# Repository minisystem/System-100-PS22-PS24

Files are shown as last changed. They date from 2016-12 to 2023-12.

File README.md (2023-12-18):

Roland System 100 Model 101/102 Power Supply Replacement
============

Replaces Roland part # PS22 (110V) or PS24 (220V). I had a Model 102 come in that was missing its power supply so I designed a replacement. It is a straight clone of the schematic from the Model 102 service manual. The BOM from the service manual can be used directly with the exception of the 2SD234 power transistors (replaced with TIP31A equivalent) and the diode bridges (replaced with individual 1N4003). 

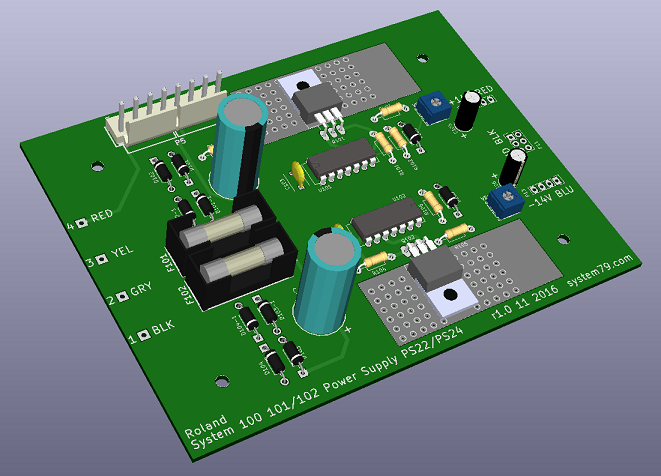
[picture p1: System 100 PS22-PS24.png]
orthoview


EDA files generated in KiCad 4.0.2. Schematic library here: https://github.com/minisystem/MyKicadLibraries/blob/master/MySynthParts.lib

KiCad GitHub libraries required as well. :/

0.156" MTA header: Molex part # 0009652088
trimmers: Bourns 3362P or equivalent

There are large copper pours top and bottom that were intended to be used as heatsinks, but they are almost certainly inadequate. Use a large external heat sink for each power transistor. The orignal heatsinks will work fine.

Mounting holes match original power supply.

Hardware design by Minisystem: jeff@minisystem.ca 

LICENSE
=======
cc-by-nc-sa
https://creativecommons.org/licenses/by-nc-sa/4.0/

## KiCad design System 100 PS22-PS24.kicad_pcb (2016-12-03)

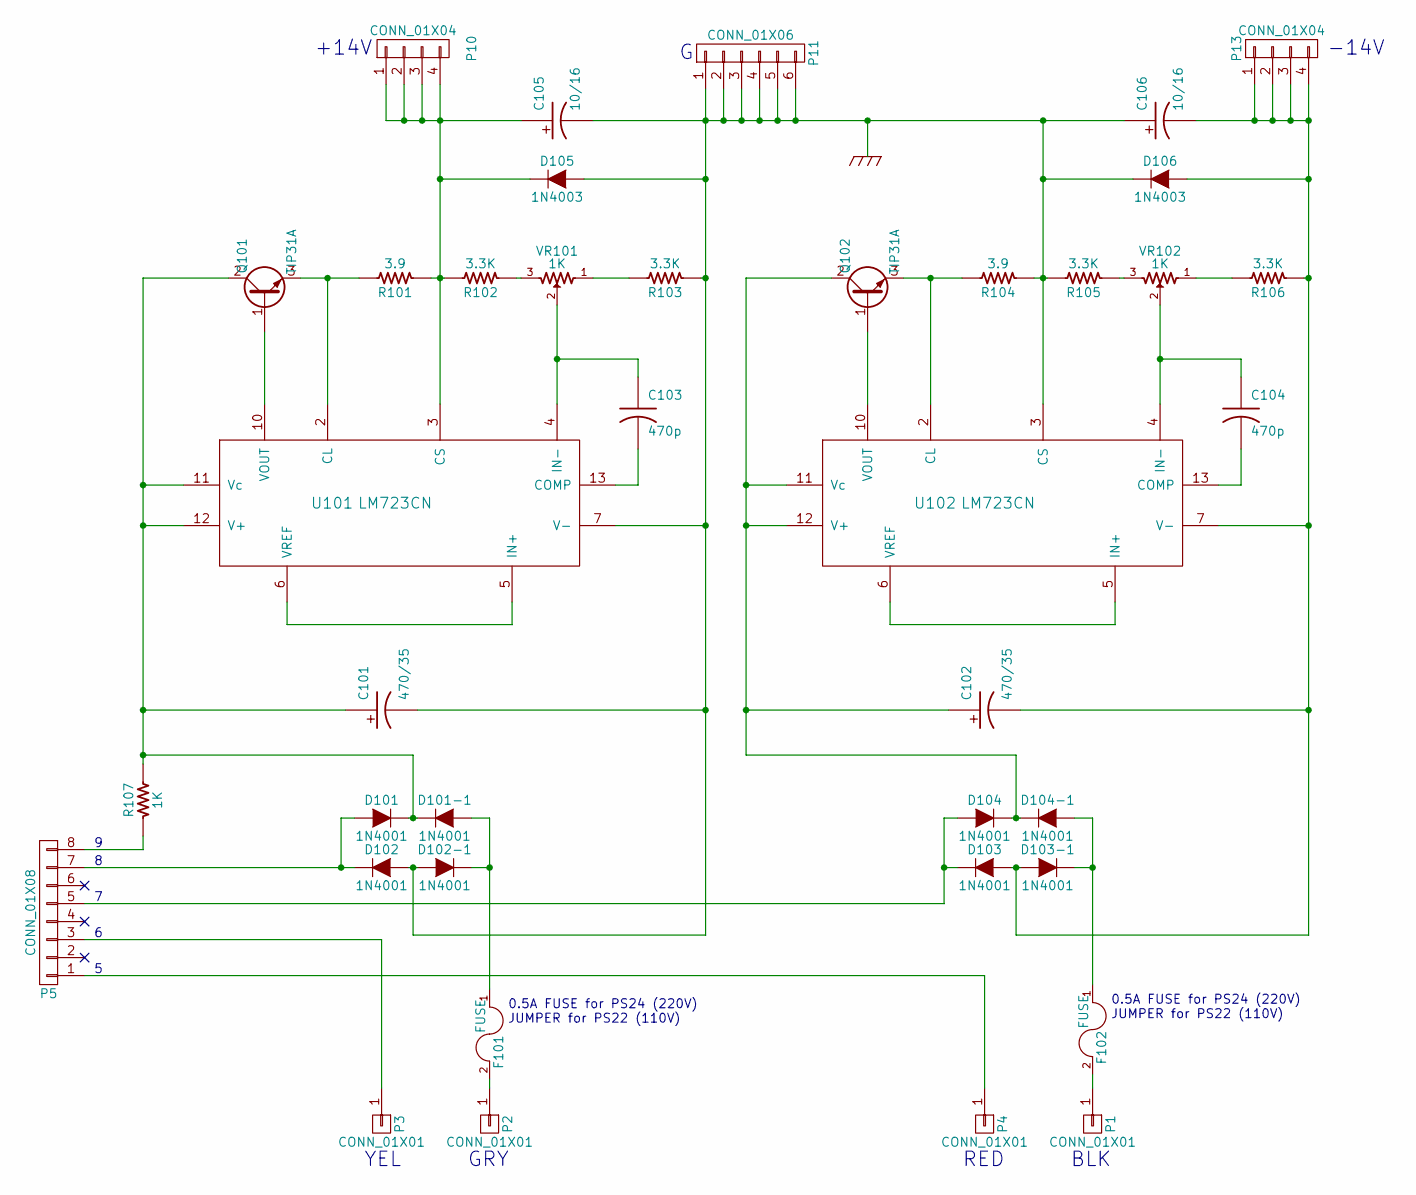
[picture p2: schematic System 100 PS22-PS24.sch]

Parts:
C101, C102: 470/35; 5MM-POL-CAP
C103, C104: 470p; C_Disc_D6_P5
C105, C106: 10/16; 2MM-POL-CAP
D101, D101-1, D102, D102-1, D103, D103-1, D104, D104-1: 1N4001; Diode_DO-41_SOD81_Horizontal_RM10
D105, D106: 1N4003; Diode_DO-41_SOD81_Horizontal_RM10
F101, F102: FUSE; Fuseholder5x20_horiz_open_inline_Type-I
P1, P2, P3, P4: CONN_01X01; Pin_Header_Straight_1x01
P5: CONN_01X08; kk156_26-60-4080
P10, P13: CONN_01X04; Pin_Header_Straight_1x04
P11: CONN_01X06; Pin_Header_Straight_2x03
Q101, Q102: TIP31A; TO-220_Neutral123_Horizontal_LargePads
R101, R104: 3.9; Resistor_Horizontal_RM10mm
R102, R103, R105, R106: 3.3K; Resistor_Horizontal_RM10mm
R107: 1K; Resistor_Horizontal_RM10mm
U101, U102: LM723CN; DIP-14_W7.62mm
VR101, VR102: 1K; Bourns_3362P

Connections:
GND: C101.2 (-), C105.2 (-), C106.1 (+), D102.2 (A), D102-1.2 (A), D105.2 (A), D106.1 (K), P11.1, P11.2, P11.3, P11.4, P11.5, P11.6, R103.1, R104.1, R105.2, U101.7 (V-), U102.3 (CS)
unnamed: C101.1 (+), D101.1 (K), D101-1.1 (K), Q101.2 (C), R107.2, U101.11 (Vc), U101.12 (V+)
unnamed: C102.1 (+), D104.1 (K), D104-1.1 (K), Q102.2 (C), U102.11 (Vc), U102.12 (V+)
unnamed: C102.2 (-), C106.2 (-), D103.2 (A), D103-1.2 (A), D106.2 (A), P13.1, P13.2, P13.3, P13.4, R106.1, U102.7 (V-)
unnamed: C103.1, U101.4 (IN-), VR101.2
unnamed: C103.2, U101.13 (COMP)
unnamed: C104.1, U102.4 (IN-), VR102.2
unnamed: C104.2, U102.13 (COMP)
unnamed: C105.1 (+), D105.1 (K), P10.1, P10.2, P10.3, P10.4, R101.1, R102.2, U101.3 (CS)
unnamed: D101-1.2 (A), D102-1.1 (K), F101.1
unnamed: D101.2 (A), D102.1 (K), P5.7
unnamed: D103-1.1 (K), D104-1.2 (A), F102.1
unnamed: D103.1 (K), D104.2 (A), P5.5
unnamed: F101.2, P2.1
unnamed: F102.2, P1.1
unnamed: P3.1, P5.3
unnamed: P4.1, P5.1
unnamed: P5.8, R107.1
unnamed: Q101.1 (B), U101.10 (VOUT)
unnamed: Q101.3 (E), R101.2, U101.2 (CL)
unnamed: Q102.1 (B), U102.10 (VOUT)
unnamed: Q102.3 (E), R104.2, U102.2 (CL)
unnamed: R102.1, VR101.3
unnamed: R103.2, VR101.1
unnamed: R105.1, VR102.3
unnamed: R106.2, VR102.1
unnamed: U101.5 (IN+), U101.6 (VREF)
unnamed: U102.5 (IN+), U102.6 (VREF)

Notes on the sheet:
+14V
-14V
0.5A FUSE for PS24 (220V) JUMPER for PS22 (110V)
YEL
GRY
RED
BLK

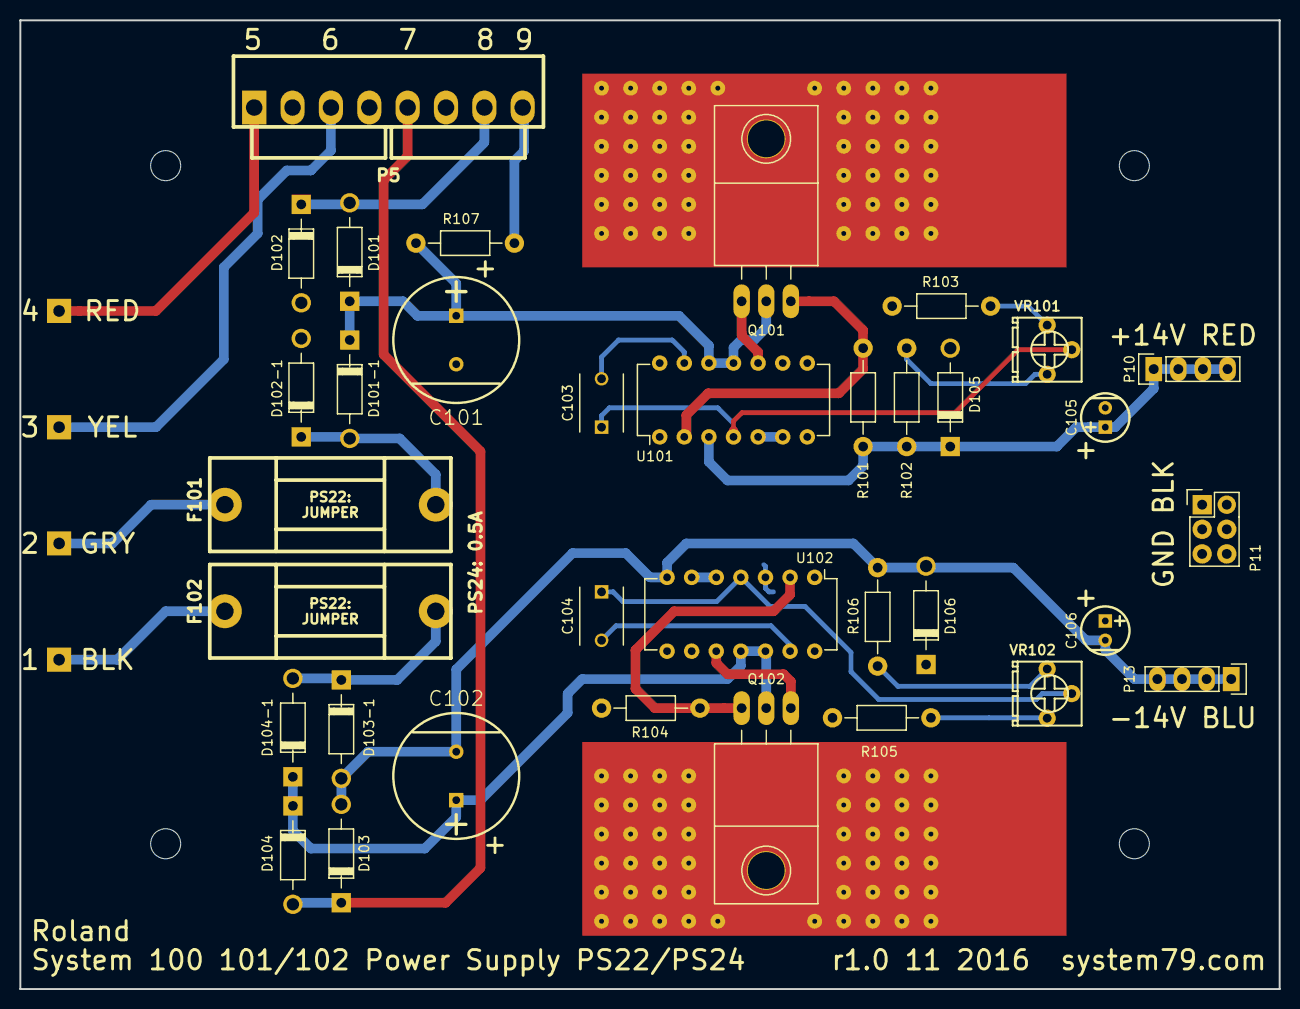
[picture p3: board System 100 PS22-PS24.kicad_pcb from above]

Board: 2 copper layers, 130.0 x 100.0 mm, 43 parts (0 on the bottom side), 28 nets.

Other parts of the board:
HOLE-M3, HOLE-M3#2, HOLE-M3#3, HOLE-M3#4: VAL**; HOLE-M3

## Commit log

2016-11-13 footprints assigned
    [System 100 PS22-PS24.sch]
2016-11-14 gerbers generated, ready to order
    [System 100 PS22-PS24.kicad_pcb, System 100 PS22-PS24.sch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]
